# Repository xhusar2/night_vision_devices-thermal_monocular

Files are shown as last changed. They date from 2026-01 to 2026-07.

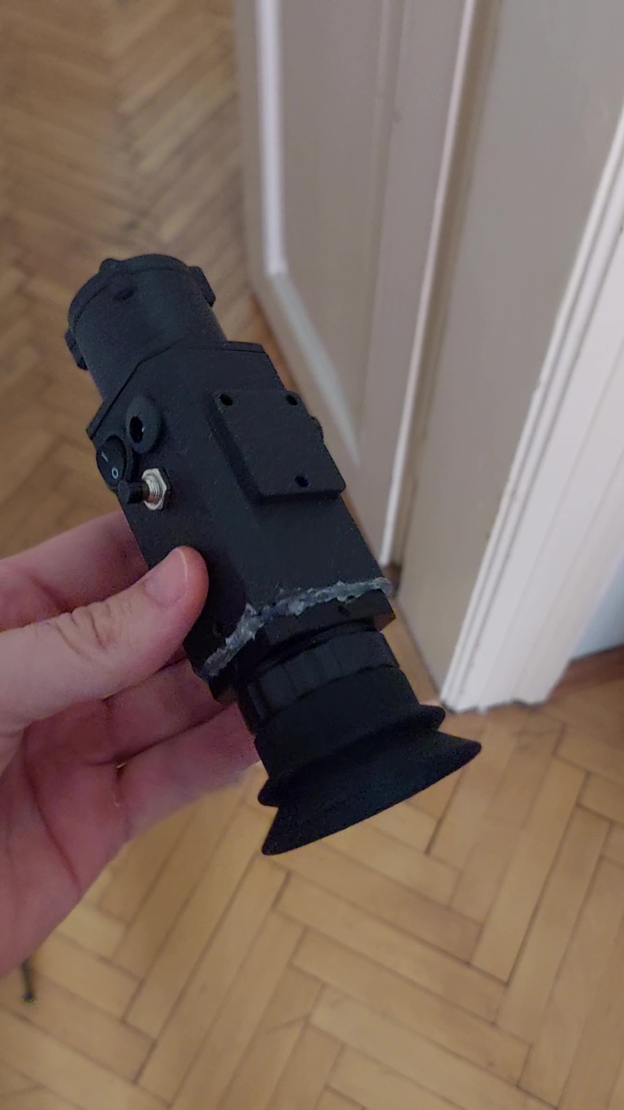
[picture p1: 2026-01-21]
resources/build_photos/finished_product_1.jpg

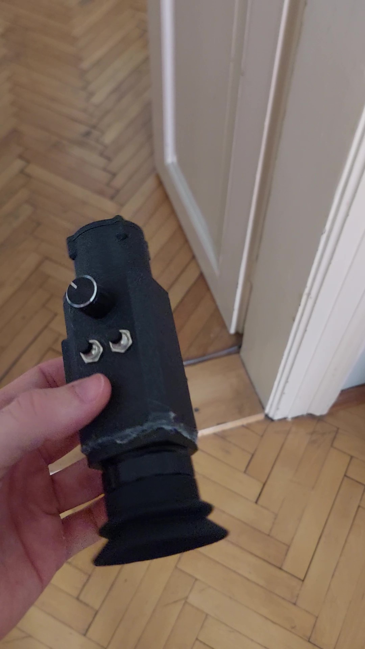
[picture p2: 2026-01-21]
resources/build_photos/finished_product_2.jpg

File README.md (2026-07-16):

# DIY Thermal Monocular — ESP32 + 256×192 Thermal Camera

> Build your own handheld thermal monocular for ~€400. Open-source firmware, 3D-printed body, RIS/Picatinny rail compatible.

<table>
  <tr>
    <td>Finished thermal monocular</td>
    <td>Thermal image result</td>
  </tr>
</table>

---

## What is this?

A fully functional **DIY thermal imaging monocular** built around a 256×192 thermal camera, an ESP32-C3 microcontroller, and a 0.39" OLED display — all packed into a 3D-printed body with an 18× eyepiece. It mounts on any standard Picatinny/RIS rail and costs a fraction of commercial thermal optics.

**Commercial thermal monoculars run €1,000–€5,000+. This build costs ~€400.**

---

## Features

- **256×192 thermal sensor** — 9mm lens, CVBS output
- **ESP32-C3** microcontroller with open-source firmware (ESP-IDF v5.5.3)
- **0.39" OLED display** with AV input — crisp image in the eyepiece
- **RIS/Picatinny rail mount** — fits standard rifle/observation setups
- **J-arm mount** option for head/helmet mounting
- **Wilcox mount** option for head/helmet mounting
- **Adjustable image orientation** — flip vertical/horizontal in firmware
- **Per-preset aiming controls** — toggle and position the crosshair from the web interface; each preset restores its saved state and position
- **Physical preset control** — release GPIO8 after a short press to change presets, or hold it for 2 seconds to toggle the current preset's crosshair
- **5.5×2.1mm DC power inlet** — run from external battery pack
- **3D-printed body** — printable on any FDM printer, all STLs included
- **Flashable via browser** — no toolchain needed for end users

---

## Specs

| Property | Value |
|---|---|
| Thermal sensor | 256×192, 9mm lens, CVBS |
| MCU | ESP32-C3 Super Mini |
| Display | 0.39" OLED (AV input) |
| Power | 5V via 5.5×2.1mm DC jack |
| Rail mount | Picatinny / RIS compatible |
| Firmware | ESP-IDF v5.5.3, open source |
| Total BOM cost | ~€400 |

---

## Repository Structure

```
├── docs/
│   ├── build-steps.md     # Full assembly guide
│   └── BOM.md             # Bill of materials with links
├── resources/
│   ├── wiring/            # KiCad schematic + PCB files
│   ├── build_photos/      # Build process photos
│   └── 3d_print/          # STL files for the body
├── compiled_binaries/     # Pre-built firmware — flash without a toolchain
└── source_code/           # ESP-IDF firmware source
```

---

## Quick Start

### Flash the pre-built firmware (no toolchain needed)

See [compiled_binaries/README.md](compiled_binaries/README.md) — flash directly from your browser or with `esptool.py`.

### Build & assemble

1. Order parts from the [Bill of Materials](docs/BOM.md)
2. Print the body STLs from `resources/3d_print/`
3. Follow the [Assembly Guide](docs/build-steps.md)

### Build firmware from source

```powershell
# In ESP-IDF CMD (Windows — use the Start Menu shortcut, not plain PowerShell)
cd source_code
idf.py set-target esp32c3
idf.py build
idf.py -p COM1 flash
```

---

## Wiring

Schematic and PCB files are in `resources/wiring/` (KiCad format). A PDF export is also included.

---

## Author

**Richard Husár** — [@xhusar2](https://github.com/xhusar2) — husarrichard@gmail.com

Licensed under the terms in [LICENSE](LICENSE).

---

## Credits

This project was inspired by [Jacob-OTW's BCOTI](https://github.com/Jacob-OTW/BCOTI/).
Many thanks for the great work that sparked this idea.

*Keywords: DIY thermal monocular, ESP32 thermal camera, open source thermal imaging, 3D printed thermal monocular, budget thermal optics, night vision DIY, OLED thermal viewer, ESP32-C3 thermal, Picatinny thermal scope*

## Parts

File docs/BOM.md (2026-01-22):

# Bill of Materials

> **Note:** Prices are approximate and may vary. Check AliExpress links for current pricing.

## Main Components

- **Thermal camera** (256x192 9MM CVBS) - ~€162.58 - [AliExpress Link](https://www.aliexpress.com/item/1005007938410808.html?spm=a2g0o.order_list.order_list_main.194.68141802FBvwr7)
- **ESP32 boards** (5PCS) - ~€2.69 - [AliExpress Link](https://www.aliexpress.com/item/1005007663345442.html?spm=a2g0o.order_list.order_list_main.209.68141802FBvwr7)
- **Eye piece** (18x) - ~€47.79 - [AliExpress Link](https://www.aliexpress.com/item/1005009392023314.html?spm=a2g0o.order_list.order_list_main.214.68141802FBvwr7)
- **0.39inch OLED display** (with AV 3Color) - ~€29.78 - [AliExpress Link](https://www.aliexpress.com/item/1005008087046449.html?spm=a2g0o.order_list.order_list_main.229.68141802FBvwr7)

## Electronics

- **Micro pins** (5pin 5set) - ~€2.32 - [AliExpress Link](https://www.aliexpress.com/item/1005008669994352.html?spm=a2g0o.order_list.order_list_main.204.68141802FBvwr7)
- **Buttons** (PBS-110 NO Black, 20pcs) - ~€3.82 - [AliExpress Link](https://www.aliexpress.com/item/1005008777027854.html?spm=a2g0o.order_list.order_list_main.224.68141802FBvwr7)
- **2-way DC power** (5.5x2.1mm) - ~€2.30 - [AliExpress Link](https://www.aliexpress.com/item/1005006375580065.html?spm=a2g0o.order_list.order_list_main.104.68141802HhpmVo)

## Total

**Total Cost:** ~€251.28

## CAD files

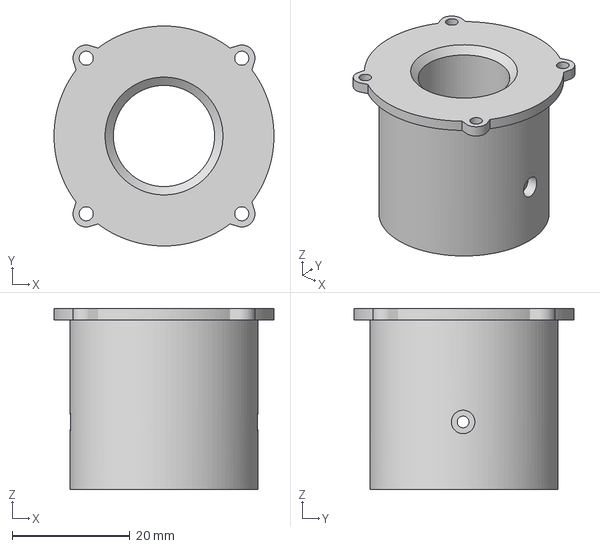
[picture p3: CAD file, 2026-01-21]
resources/3d_print/Thermal_housing_camarea_case.3mf
37.4 x 37.4 x 30.8 mm

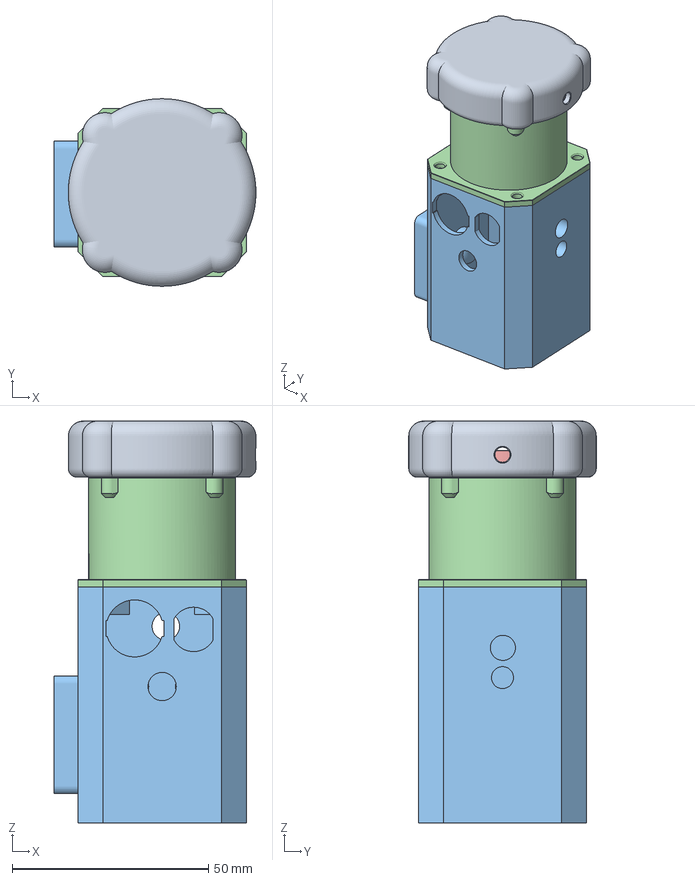
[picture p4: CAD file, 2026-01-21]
resources/3d_print/Thermal_housing.3mf
51.4 x 47.7 x 102.3 mm
Cap
Housing (1)
Main_body
Main_body_lid
Mesh_Protector

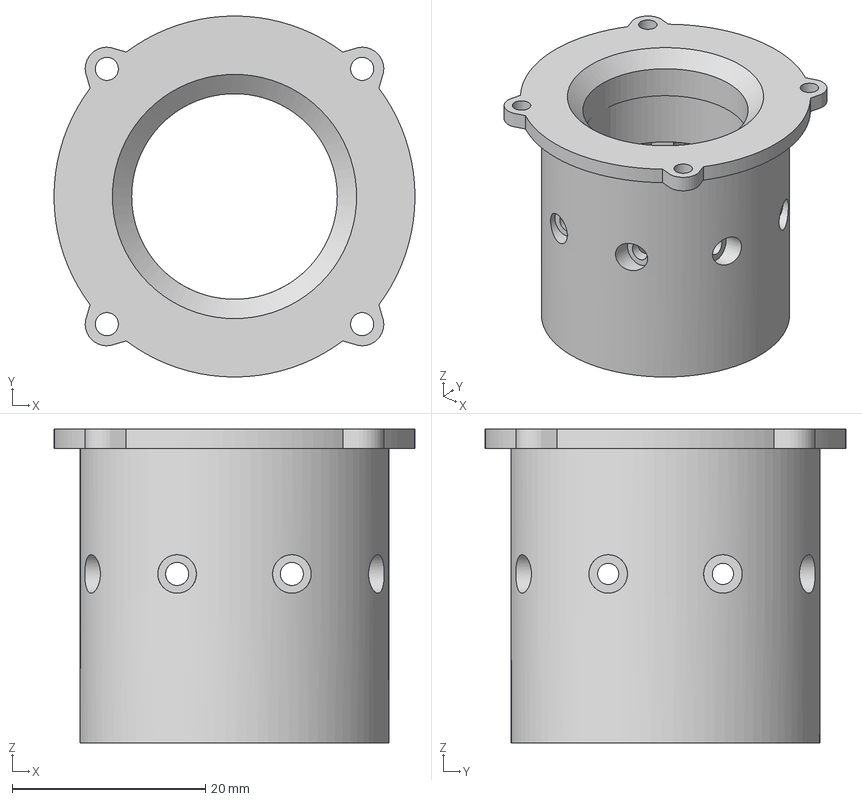
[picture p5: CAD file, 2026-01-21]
resources/3d_print/Thermal_camera_housing.3mf
37.4 x 37.4 x 32.5 mm

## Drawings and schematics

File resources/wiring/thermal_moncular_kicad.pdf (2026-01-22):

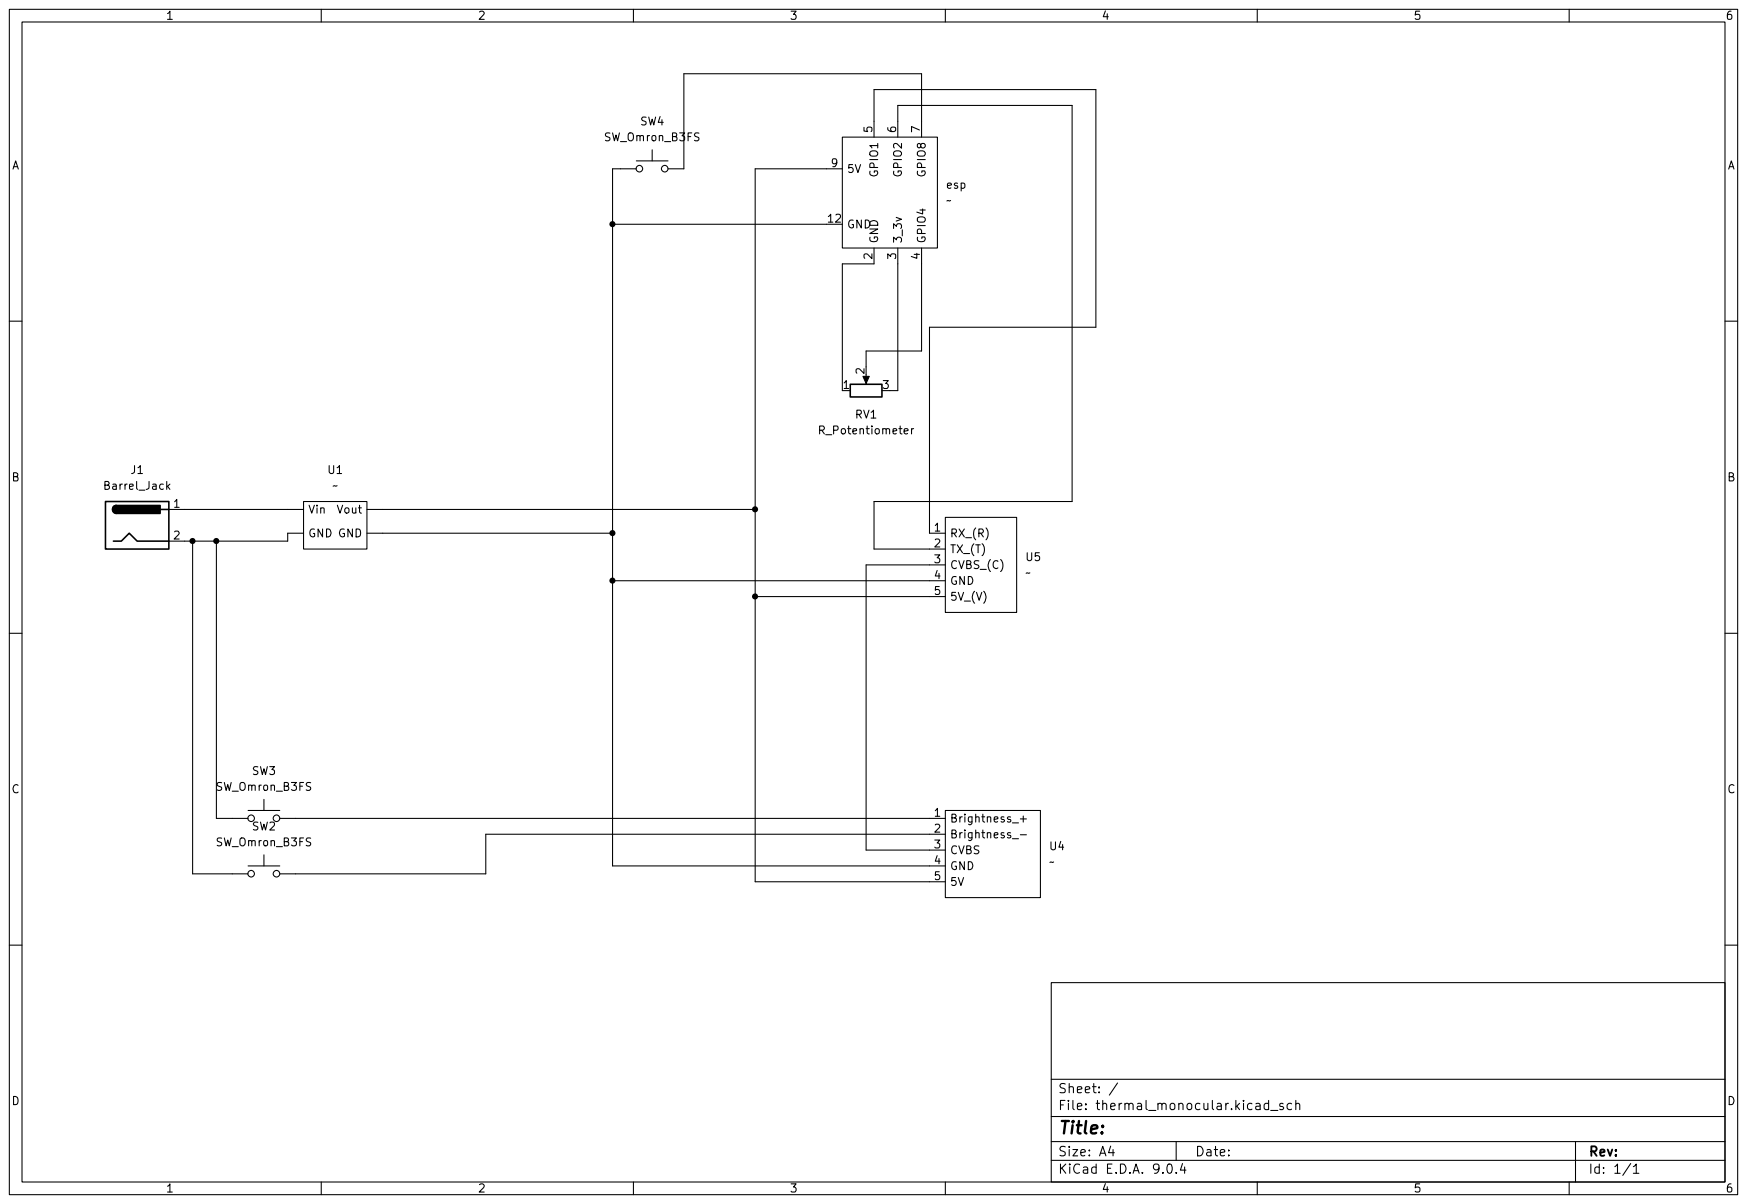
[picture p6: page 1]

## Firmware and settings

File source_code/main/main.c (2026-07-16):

#include <stdio.h>
#include <stdlib.h>
#include <string.h>
#include "esp_wifi.h"
#include "esp_mac.h"
#include "esp_event.h"
#include "lwip/err.h"
#include "lwip/sys.h"
#include "esp_log.h"
#include "nvs_flash.h"
#include "esp_http_server.h"
#include "esp_system.h"
#include "json_parser.h"
#include "esp_adc/adc_oneshot.h"
#include "esp_timer.h"
#include "driver/gpio.h"
#include "Mini2.h"
#include "control_validation.h"

#define TAG "MAIN"

#define SSID "THERMAL_MONOCULAR"
#define PASSWORD "password123"
#define PRESET_COUNT 3
#define FIRMWARE_VERSION "0.4.12"
#define BUTTON_DEBOUNCE_US (50 * 1000)
#define BUTTON_LONG_PRESS_US (2 * 1000 * 1000)
#define PERSIST_ATTEMPTS 3

#define UART_TX GPIO_NUM_1
#define UART_RX GPIO_NUM_2
#define POTI_PIN GPIO_NUM_4
#define MULTI_BTN GPIO_NUM_8


extern const uint8_t index_html_start[] asm("_binary_index_html_start");
extern const uint8_t index_html_end[]   asm("_binary_index_html_end");

static esp_netif_t *sta_netif = NULL;

nvs_handle_t flash_handle;

int8_t brightness_button_count = 0;

typedef struct stored_values_t{
    uint8_t active_preset;
    alignment_preset_t alignment;
    value_preset_t presets[PRESET_COUNT];
    bool first_boot;
} stored_values_t;

value_preset_t default_presets[] = {
    {
        .preset_en = true,
        .pseudo_color = WHOT,
        .scene_mode = GeneralMode,
        .contrast = 100,
        .edge_enhancment_gear = 1,
        .detail_enhancement_gear = 55,
        .burn_protection_en = true,
        .auto_shutter_en = true,
    },
    {
        .preset_en = true,
        .pseudo_color = WHOT,
        .scene_mode = Outline,
        .contrast = 100,
        .edge_enhancment_gear = 1,
        .detail_enhancement_gear = 50,
        .burn_protection_en = true,
        .auto_shutter_en = true,
    }
};

value_preset_t base_preset = {
    .preset_en = false,
    .pseudo_color = WHOT,
    .scene_mode = GeneralMode,
    .contrast = 50,
    .edge_enhancment_gear = 1,
    .detail_enhancement_gear = 50,
    .burn_protection_en = true,
    .auto_shutter_en = true,
};

stored_values_t stored = {
    .active_preset = 0,
    .alignment = {
        .zoom = 10,
        .zoom_x = 128,
        .zoom_y = 96,
        .av_format = PAL,
        .flip_mode = No_Flip,
        .fps = Hz50,
        .refresh_flip_mode = false,
    },
    .first_boot = true
};

static uint8_t crosshair_preset_mask = 0;
typedef struct {
    uint16_t x[PRESET_COUNT];
    uint16_t y[PRESET_COUNT];
} crosshair_positions_t;
static crosshair_positions_t crosshair_positions = {
    .x = {128, 128, 128},
    .y = {96, 96, 96},
};
typedef struct {
    uint8_t spatial[PRESET_COUNT];
    uint8_t temporal[PRESET_COUNT];
    uint8_t gamma[PRESET_COUNT];
    uint8_t spatial_mask;
    uint8_t temporal_mask;
    uint8_t gamma_mask;
} image_controls_t;
static image_controls_t image_controls;
static bool wifi_next_boot = false;
static esp_err_t boot_analog_video_initial_status = ESP_ERR_INVALID_STATE;
static volatile uint8_t last_applied_preset;
static bool camera_state_authoritative = true;
static esp_err_t camera_state_status = ESP_OK;
static bool persistence_authoritative = true;
static esp_err_t persistence_status = ESP_OK;

static bool preset_crosshair_enabled(uint8_t preset) {
    return (crosshair_preset_mask & (1U << preset)) != 0;
}

static void set_preset_crosshair_enabled(uint8_t preset, bool enabled) {
    if (enabled) {
        crosshair_preset_mask |= (1U << preset);
    } else {
        crosshair_preset_mask &= ~(1U << preset);
    }
}

static esp_err_t commit_settings(void) {
    esp_err_t err = nvs_set_blob(flash_handle, "stored_values", &stored, sizeof(stored));
    if (err == ESP_OK) {
        err = nvs_set_u8(flash_handle, "crosshair_mask", crosshair_preset_mask);
    }
    if (err == ESP_OK) {
        err = nvs_set_u8(flash_handle, "wifi_next", wifi_next_boot);
    }
    if (err == ESP_OK) {
        err = nvs_set_blob(flash_handle, "image_controls", &image_controls, sizeof(image_controls));
    }
    if (err == ESP_OK) {
        err = nvs_set_blob(flash_handle, "cursor_pos", &crosshair_positions, sizeof(crosshair_positions));
    }
    return err == ESP_OK ? nvs_commit(flash_handle) : err;
}

static int persist_settings(void *context) {
    (void)context;
    return commit_settings();
}

static esp_err_t commit_settings_with_retry(void) {
    return control_retry_operation(NULL, persist_settings, PERSIST_ATTEMPTS);
}

static bool json_obj_has_key(const jparse_ctx_t *jctx, const char *key) {
    const int object_index = jctx->cur - jctx->tokens;
    const size_t key_length = strlen(key);

    for (int i = object_index + 1; i < jctx->num_tokens; i++) {
        const json_tok_t *token = &jctx->tokens[i];
        if (token->parent == object_index && token->type == JSMN_STRING &&
            (size_t)(token->end - token->start) == key_length &&
            strncmp(jctx->js + token->start, key, key_length) == 0) {
            return true;
        }
    }

    return false;
}

Mini2_t cam = {
    .uart_port = UART_NUM_1, // C3 only has num0 and num1, and num0 is used for debug / USB_CDC
    .uart_tx = UART_TX,
    .uart_rx = UART_RX,
    .variant = Mini2_256
};

static int apply_preset_step(void *context, uint8_t preset) {
    Mini2_t *camera = context;
    return Mini2_apply_preset(camera, &stored.presets[preset], &stored.alignment, true);
}

static int apply_crosshair_step(void *context, bool enabled) {
    return Mini2_set_crosshair(context, enabled);
}

static esp_err_t apply_preset_with_crosshair(uint8_t preset) {
    esp_err_t err = control_apply_preset_transaction(
        &cam, preset, preset_crosshair_enabled(preset),
        apply_preset_step, apply_crosshair_step);
    if (err != ESP_OK) {
        return err;
    }
    err = Mini2_set_crosshair_position(&cam, crosshair_positions.x[preset],
                                       crosshair_positions.y[preset]);
    if (image_controls.spatial_mask & (1U << preset))
        err = Mini2_set_spatial_noise_reduction(&cam, image_controls.spatial[preset]);
    if (err == ESP_OK && (image_controls.temporal_mask & (1U << preset)))
        err = Mini2_set_temporal_noise_reduction(&cam, image_controls.temporal[preset]);
    if (err == ESP_OK && (image_controls.gamma_mask & (1U << preset)))
        err = Mini2_set_gamma_intensity(&cam, image_controls.gamma[preset]);
    if (err != ESP_OK) return err;
    last_applied_preset = preset;
    return ESP_OK;
}

static esp_err_t restore_camera_snapshot(const stored_values_t *snapshot,
                                         uint8_t snapshot_crosshair_mask) {
    const uint8_t preset_index = snapshot->active_preset;
    const value_preset_t *preset = &snapshot->presets[preset_index];
    esp_err_t err = ESP_OK;

    err = control_first_error(err, Mini2_set_color_pallet(&cam, preset->pseudo_color));
    err = control_first_error(err, Mini2_set_scene_mode(&cam, preset->scene_mode));
    err = control_first_error(err, Mini2_set_contrast(&cam, preset->contrast));
    err = control_first_error(err, Mini2_set_edge_enhancment(&cam, preset->edge_enhancment_gear));
    err = control_first_error(err, Mini2_set_detail_enhancement(&cam, preset->detail_enhancement_gear));
    err = control_first_error(err, Mini2_set_burn_protection(&cam, preset->burn_protection_en));
    err = control_first_error(err, Mini2_set_auto_shutter(&cam, preset->auto_shutter_en));
    if (image_controls.spatial_mask & (1U << preset_index))
        err = control_first_error(err, Mini2_set_spatial_noise_reduction(&cam, image_controls.spatial[preset_index]));
    if (image_controls.temporal_mask & (1U << preset_index))
        err = control_first_error(err, Mini2_set_temporal_noise_reduction(&cam, image_controls.temporal[preset_index]));
    if (image_controls.gamma_mask & (1U << preset_index))
        err = control_first_error(err, Mini2_set_gamma_intensity(&cam, image_controls.gamma[preset_index]));
    err = control_first_error(err, Mini2_set_analog_video_format(&cam, snapshot->alignment.av_format));
    err = control_first_error(err, Mini2_set_flip_mode(&cam, snapshot->alignment.flip_mode));
    err = control_first_error(err, Mini2_set_point_zoom(
        &cam, snapshot->alignment.zoom_x, snapshot->alignment.zoom_y,
        snapshot->alignment.zoom));
    err = control_first_error(err, Mini2_set_crosshair(
        &cam, (snapshot_crosshair_mask & (1U << preset_index)) != 0));
    err = control_first_error(err, Mini2_set_crosshair_position(
        &cam, crosshair_positions.x[preset_index], crosshair_positions.y[preset_index]));

    if (err == ESP_OK) {
        last_applied_preset = preset_index;
    }
    return err;
}

static void wifi_event_handler(void* arg, esp_event_base_t event_base, int32_t event_id, void* event_data) {
    if (event_id == WIFI_EVENT_AP_STACONNECTED) {
        wifi_event_ap_staconnected_t* event = (wifi_event_ap_staconnected_t*) event_data;
        ESP_LOGI(TAG, "station "MACSTR" join, AID=%d",
                 MAC2STR(event->mac), event->aid);
    } else if (event_id == WIFI_EVENT_AP_STADISCONNECTED) {
        wifi_event_ap_stadisconnected_t* event = (wifi_event_ap_stadisconnected_t*) event_data;
        ESP_LOGI(TAG, "station "MACSTR" leave, AID=%d, reason=%d",
                 MAC2STR(event->mac), event->aid, event->reason);
    }
}

static uint8_t next_preset(uint8_t current) {
    do {
        current = (current + 1) % PRESET_COUNT;
    } while (current != 0 && !stored.presets[current].preset_en);
    return current;
}

static esp_err_t switch_preset(uint8_t preset) {
    const stored_values_t previous = stored;
    const uint8_t previous_crosshair_mask = crosshair_preset_mask;
    esp_err_t err = apply_preset_with_crosshair(preset);
    if (err == ESP_OK) {
        stored.active_preset = preset;
        camera_state_authoritative = true;
        camera_state_status = ESP_OK;
    } else {
        esp_err_t rollback_err = restore_camera_snapshot(&previous, previous_crosshair_mask);
        camera_state_authoritative = rollback_err == ESP_OK;
        camera_state_status = rollback_err == ESP_OK ? err : rollback_err;
        ESP_LOGE(TAG, "Preset %u apply failed (%s), rollback %s", preset,
                 esp_err_to_name(err), rollback_err == ESP_OK ? "succeeded" : "failed");
    }
    return err;
}


static esp_err_t rollback_preset(uint8_t preset) {
    stored_values_t snapshot = stored;
    snapshot.active_preset = preset;
    esp_err_t err = restore_camera_snapshot(&snapshot, crosshair_preset_mask);
    if (err == ESP_OK) {
        stored = snapshot;
        esp_err_t commit_err = commit_settings_with_retry();
        persistence_authoritative = control_commit_is_authoritative(commit_err);
        persistence_status = commit_err;
    }
    camera_state_authoritative = err == ESP_OK;
    camera_state_status = err;
    return err;
}
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
void app_main(void) {
    ESP_ERROR_CHECK(nvs_flash_init());

    for (int i=0; i<PRESET_COUNT; i++) {
        stored.presets[i] = i < (sizeof(default_presets) / sizeof(value_preset_t))
            ? default_presets[i] : base_preset;
    }

    ESP_ERROR_CHECK(nvs_open("storage", NVS_READWRITE, &flash_handle));
    size_t len = sizeof(stored_values_t);
    esp_err_t err = nvs_get_blob(flash_handle, "stored_values", &stored, &len);
    if (err != ESP_OK) {
        ESP_LOGI(TAG, "Failed to read stored values from NVS, going with defaults.");
    }
    uint8_t persisted_value = 0;
    if (nvs_get_u8(flash_handle, "crosshair_mask", &persisted_value) == ESP_OK) {
        crosshair_preset_mask = persisted_value & ((1U << PRESET_COUNT) - 1U);
    } else if (nvs_get_u8(flash_handle, "crosshair_en", &persisted_value) == ESP_OK && persisted_value != 0) {
        crosshair_preset_mask = (1U << PRESET_COUNT) - 1U;
    }
    size_t image_controls_len = sizeof(image_controls);
    if (nvs_get_blob(flash_handle, "image_controls", &image_controls,
                     &image_controls_len) != ESP_OK ||
        image_controls_len != sizeof(image_controls)) {
        memset(&image_controls, 0, sizeof(image_controls));
    }
    size_t cursor_positions_len = sizeof(crosshair_positions);
    uint8_t cursor_migrated = 0;
    if (nvs_get_blob(flash_handle, "cursor_pos", &crosshair_positions,
                     &cursor_positions_len) != ESP_OK ||
        cursor_positions_len != sizeof(crosshair_positions)) {
        for (int i = 0; i < PRESET_COUNT; i++) {
            crosshair_positions.x[i] = stored.alignment.zoom_x < cam.variant.sensor_width
                ? stored.alignment.zoom_x : cam.variant.sensor_width - 1;
            crosshair_positions.y[i] = stored.alignment.zoom_y < cam.variant.sensor_height
                ? stored.alignment.zoom_y : cam.variant.sensor_height - 1;
        }
    }
    if (nvs_get_u8(flash_handle, "cursor_migrated", &cursor_migrated) != ESP_OK ||
        cursor_migrated == 0) {
        stored.alignment.zoom = 10;
        stored.alignment.zoom_x = cam.variant.sensor_width / 2;
        stored.alignment.zoom_y = cam.variant.sensor_height / 2;
        ESP_ERROR_CHECK(nvs_set_u8(flash_handle, "cursor_migrated", 1));
        ESP_ERROR_CHECK(commit_settings());
    }
    persisted_value = 0;
    if (nvs_get_u8(flash_handle, "wifi_next", &persisted_value) == ESP_OK) {
        wifi_next_boot = persisted_value != 0;
    }

    gpio_config_t io_conf = {
        .intr_type = GPIO_INTR_DISABLE,
        .mode = GPIO_MODE_INPUT,
        .pin_bit_mask = (1ULL << MULTI_BTN),
        .pull_down_en = GPIO_PULLDOWN_DISABLE,
        .pull_up_en = GPIO_PULLUP_ENABLE,
    };
    gpio_config(&io_conf);

    bool wifi_en = (gpio_get_level(MULTI_BTN) == 0) || stored.first_boot || wifi_next_boot;
    if (wifi_next_boot) {
        wifi_next_boot = false;
        ESP_ERROR_CHECK(commit_settings());
    }
    ESP_LOGI(TAG, "Wifi: %d", (int)wifi_en);

    if (wifi_en) {
        ESP_ERROR_CHECK(esp_netif_init());
        ESP_ERROR_CHECK(esp_event_loop_create_default());
        sta_netif = esp_netif_create_default_wifi_ap();
        wifi_init_config_t cfg = WIFI_INIT_CONFIG_DEFAULT();
        ESP_ERROR_CHECK(esp_wifi_init(&cfg));
        ESP_ERROR_CHECK(esp_event_handler_instance_register(WIFI_EVENT,
                                                        ESP_EVENT_ANY_ID,
                                                        &wifi_event_handler,
                                                        NULL,
                                                        NULL));
        wifi_config_t wifi_config = {
            .ap = {
                .ssid = SSID,
                .ssid_len = strlen(SSID),
                .password = PASSWORD,
                .channel = 1,
                .max_connection = 4,
                .authmode = WIFI_AUTH_WPA2_PSK,
                .pmf_cfg = {
                    .required = true,
                },
            }
        };
        ESP_ERROR_CHECK(esp_wifi_set_mode(WIFI_MODE_AP));
        ESP_ERROR_CHECK(esp_wifi_set_config(WIFI_IF_AP, &wifi_config) );
        ESP_ERROR_CHECK(esp_wifi_start());
    }

    ESP_LOGI(TAG, "Waiting 5000 ms before Mini2 UART initialization");
    vTaskDelay(pdMS_TO_TICKS(5000));
    Mini2_init(&cam);
    ESP_LOGI(TAG, "Mini2 UART initialized at %lld ms", esp_timer_get_time() / 1000);

    boot_analog_video_initial_status = Mini2_apply_preset(&cam, &stored.presets[stored.active_preset], &stored.alignment, false);
    if (boot_analog_video_initial_status == ESP_OK) {
        ESP_LOGI(TAG, "Mini2 boot warm-up started at %lld ms", esp_timer_get_time() / 1000);
        vTaskDelay(pdMS_TO_TICKS(2500));
        ESP_LOGI(TAG, "Mini2 boot warm-up completed at %lld ms", esp_timer_get_time() / 1000);
        boot_analog_video_initial_status = Mini2_set_crosshair(&cam, preset_crosshair_enabled(stored.active_preset));
    }
    if (boot_analog_video_initial_status == ESP_OK) {
        boot_analog_video_initial_status = Mini2_set_crosshair_position(
            &cam, crosshair_positions.x[stored.active_preset],
            crosshair_positions.y[stored.active_preset]);
    }
    if (boot_analog_video_initial_status == ESP_OK &&
        (image_controls.spatial_mask & (1U << stored.active_preset)))
        boot_analog_video_initial_status = Mini2_set_spatial_noise_reduction(&cam, image_controls.spatial[stored.active_preset]);
    if (boot_analog_video_initial_status == ESP_OK &&
        (image_controls.temporal_mask & (1U << stored.active_preset)))
        boot_analog_video_initial_status = Mini2_set_temporal_noise_reduction(&cam, image_controls.temporal[stored.active_preset]);
    if (boot_analog_video_initial_status == ESP_OK &&
        (image_controls.gamma_mask & (1U << stored.active_preset)))
        boot_analog_video_initial_status = Mini2_set_gamma_intensity(&cam, image_controls.gamma[stored.active_preset]);
    last_applied_preset = stored.active_preset;
    if (boot_analog_video_initial_status == ESP_OK) {
        camera_state_authoritative = true;
        camera_state_status = ESP_OK;
        ESP_LOGI(TAG, "Boot video save/apply initialization succeeded");
    } else {
        camera_state_authoritative = false;
        camera_state_status = boot_analog_video_initial_status;
        ESP_LOGE(TAG, "Boot video save/apply initialization failed: %s", esp_err_to_name(boot_analog_video_initial_status));
    }
    xTaskCreate(loop_task, "loop task", 16384, NULL, 5, NULL);

    if (wifi_en) {
        httpd_handle_t server = NULL;
        httpd_config_t config = HTTPD_DEFAULT_CONFIG();
        config.lru_purge_enable = true;

        ESP_LOGI(TAG, "Starting server on port: '%d'", config.server_port);
        if (httpd_start(&server, &config) == ESP_OK) {
            ESP_LOGI(TAG, "Registering URI handlers");
            httpd_register_uri_handler(server, &echo);
            httpd_register_uri_handler(server, &index_uri);
            httpd_register_uri_handler(server, &retireve_values_route);
        }
    }

}

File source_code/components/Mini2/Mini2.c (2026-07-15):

#include "Mini2.h"

uint16_t crc16_xmodem(uint8_t* data, size_t len) {
    uint16_t crc = 0;
    for (int i=0; i<len; i++) {
        crc ^= (data[i] << 8);
        for (int j=0; j<8; j++) {
            if (crc & 0x8000) {
                crc = (crc << 1) ^ 0x1021;
            } else {
                crc <<= 1;
            }
        }
    }
    return crc;
}

void Mini2_init(Mini2_t* cam) {
    uart_config_t uart_config = {
        .baud_rate = 115200,
        .data_bits = UART_DATA_8_BITS,
        .parity = UART_PARITY_DISABLE,
        .stop_bits = UART_STOP_BITS_1,
        .flow_ctrl = UART_HW_FLOWCTRL_DISABLE,
        .source_clk = UART_SCLK_DEFAULT,
    };

    ESP_ERROR_CHECK(uart_driver_install(cam->uart_port, 2048, 0, 0, NULL, 0));
    ESP_ERROR_CHECK(uart_param_config(cam->uart_port, &uart_config));
    ESP_ERROR_CHECK(uart_set_pin(cam->uart_port, cam->uart_tx, cam->uart_rx, -1, -1));
}

esp_err_t Mini2_write_command(Mini2_t* cam, uint8_t* cmd, size_t len) {
    uint8_t full_cmd[] = {0x55, 0x43, 0x49, 0x12, 0x00, 0x00 /*command class*/, 0x00 /*command index*/, 0x00 /*sub command*/, 0x00 /*reserved*/, 0x00, 0x00, 0x00, 0x00 /*4byte Parameter1*/, 0x00, 0x00, 0x00, 0x00 /*4byte Parameter2*/, 0x00, 0x00 /*Read length, 0 when writing*/, 0x00, 0x00 /*2btyes Reserved*/, 0x00, 0x00 /*2byte crc16 xmodem*/};

    if (len > 16) {
        ESP_LOGE(Mini2_TAG, "command length may not be longer than 16bytes");
        return ESP_FAIL;
    }

    memcpy(full_cmd + 5, cmd, len);
    uint16_t checksum = crc16_xmodem(full_cmd + 5, 16);
    memcpy(full_cmd + 21, &checksum, 2);

    ESP_LOG_BUFFER_HEXDUMP(Mini2_TAG, full_cmd, sizeof(full_cmd), ESP_LOG_INFO);
    
    for (int i=0; i < sizeof(full_cmd); i++) {
        int bytes_written = uart_write_bytes(cam->uart_port, full_cmd + i, 1);
        if (bytes_written == -1) {
            ESP_LOGE(Mini2_TAG, "Failed to write byte%d command to UART", i);
            return ESP_FAIL;
        }   
    }

    return ESP_OK;
}

esp_err_t Mini2_read_command(Mini2_t* cam, uint8_t* cmd, size_t len, uint8_t* out_buf, size_t* out_len) {
    esp_err_t err_code;
    const size_t expected_len = *out_len;

    memset(out_buf, 0, expected_len);

    uart_flush(cam->uart_port);
    err_code = Mini2_write_command(cam, cmd, len);
    if (err_code != ESP_OK) {
        return err_code;
    }
    int bytes_read = uart_read_bytes(cam->uart_port, out_buf, *out_len, pdMS_TO_TICKS(200));
    if (bytes_read <= 0 || (size_t)bytes_read != expected_len) {
        *out_len = bytes_read > 0 ? (size_t)bytes_read : 0;
        return ESP_FAIL;
    }

    ESP_LOG_BUFFER_HEXDUMP("UART_READ", out_buf, bytes_read, ESP_LOG_INFO);

    *out_len = bytes_read;
    return ESP_OK;
}

esp_err_t Mini2_get_flip_mode(Mini2_t* cam, enum FlipMode* flip_mode_out) {
    uint8_t rx_buffer[10];
    size_t len = sizeof(rx_buffer);

    uint8_t cmd[] = {0x10, 0x10, 0x83, 0x00, 0x00, 0x00, 0x00, 0x00, 0x00, 0x00, 0x00, 0x00, 0x01};
    esp_err_t err_code = Mini2_read_command(cam, cmd, sizeof(cmd), rx_buffer, &len);
    if (err_code != ESP_OK) {
        return err_code;
    }
    
    if (!(rx_buffer[0] == 0xBE && rx_buffer[1] == 0xAA && rx_buffer[8] == 0xEB && rx_buffer[9] == 0xAA)) {
        return ESP_FAIL;
    }

    *flip_mode_out = (enum FlipMode)rx_buffer[5];
    return ESP_OK;
}

esp_err_t Mini2_set_color_pallet(Mini2_t* cam, enum PseudoColor pseudo_color) {
    uint8_t cmd[] = {0x10, 0x03, 0x45, 0x00, 0x00, pseudo_color};
    return Mini2_write_command(cam, cmd, sizeof(cmd));
}

esp_err_t Mini2_set_scene_mode(Mini2_t* cam, enum SceneMode scene_mode) {
    uint8_t cmd[] = {0x10, 0x04, 0x42, 0x00, scene_mode};
    return Mini2_write_command(cam, cmd, sizeof(cmd));
}

esp_err_t Mini2_set_flip_mode(Mini2_t* cam, enum SceneMode FlipMode) {
    uint8_t cmd[] = {0x10, 0x10, 0x43, 0x00, FlipMode};
    return Mini2_write_command(cam, cmd, sizeof(cmd));
}

esp_err_t Mini2_set_analog_video_format(Mini2_t* cam, enum AnalogVideoFormat av_format) {
    uint8_t cmd[] = {0x10, 0x10, 0x4A, 0x00, 0x01, av_format};
    return Mini2_write_command(cam, cmd, sizeof(cmd));
}

esp_err_t Mini2_get_analog_video_format(Mini2_t* cam, enum AnalogVideoFormat* av_format_out) {
    uint8_t rx_buffer[11] = {0};
    size_t len = sizeof(rx_buffer);

    uint8_t cmd[] = {0x10, 0x10, 0x8a, 0x00, 0x00, 0x00, 0x00, 0x00, 0x00, 0x00, 0x00, 0x00, 0x02};
    esp_err_t err_code = Mini2_read_command(cam, cmd, sizeof(cmd), rx_buffer, &len);
    if (err_code != ESP_OK) {
        return err_code;
    }

    if (!(rx_buffer[0] == 0xBE && rx_buffer[1] == 0xAA && rx_buffer[9] == 0xEB && rx_buffer[10] == 0xAA)) {
        return ESP_FAIL;
    }

    *av_format_out = (enum AnalogVideoFormat)rx_buffer[6];
    return ESP_OK;
}

esp_err_t Mini2_set_digital_video_format(Mini2_t* cam, bool enabled, enum DigitalVideoFormat video_format, enum DetectorRefreshRate fps) {
    uint8_t cmd[] = {0x10, 0x10, 0x46, 0x00, (uint8_t)enabled, (uint8_t)video_format, (uint8_t)fps};
    return Mini2_write_command(cam, cmd, sizeof(cmd));
}

esp_err_t Mini2_save_video(Mini2_t* cam) {
    uint8_t cmd[] = {0x10, 0x10, 0x49};
    return Mini2_write_command(cam, cmd, sizeof(cmd));
}

esp_err_t Mini2_set_brightness(Mini2_t* cam, uint8_t brightness) {
    if (brightness > 100) {
        ESP_LOGE(Mini2_TAG, "Brightness must be <= 100");
        return ESP_FAIL;
    }
    uint8_t cmd[] = {0x10, 0x04, 0x47, 0x00, brightness};
    return Mini2_write_command(cam, cmd, sizeof(cmd));
}

esp_err_t Mini2_set_contrast(Mini2_t* cam, uint8_t contrast) {
    if (contrast > 100) {
        ESP_LOGE(Mini2_TAG, "Contrast must be <= 100");
        return ESP_FAIL;
    }
    uint8_t cmd[] = {0x10, 0x04, 0x4A, 0x00, contrast};
    return Mini2_write_command(cam, cmd, sizeof(cmd));
}

esp_err_t Mini2_set_edge_enhancment(Mini2_t* cam, uint8_t gear) {
    if (gear > 2) {
        ESP_LOGE(Mini2_TAG, "Edge enhancment gear must be <= 2");
        return ESP_FAIL;
    }
    uint8_t cmd[] = {0x10, 0x04, 0x4E, 0x00, gear};
    return Mini2_write_command(cam, cmd, sizeof(cmd));
}

esp_err_t Mini2_set_detail_enhancement(Mini2_t* cam, uint8_t gear) {
    if (gear > 100) {
        ESP_LOGE(Mini2_TAG, "Detail enhancement gear must be <= 100");
        return ESP_FAIL;
    }
    uint8_t cmd[] = {0x10, 0x04, 0x45, 0x00, gear};
    return Mini2_write_command(cam, cmd, sizeof(cmd));
}

esp_err_t Mini2_set_spatial_noise_reduction(Mini2_t* cam, uint8_t value) {
    uint8_t cmd[] = {0x10, 0x04, 0x4B, 0x00, value};
    return Mini2_write_command(cam, cmd, sizeof(cmd));
}

esp_err_t Mini2_set_temporal_noise_reduction(Mini2_t* cam, uint8_t value) {
    uint8_t cmd[] = {0x10, 0x04, 0x4C, 0x00, value};
    return Mini2_write_command(cam, cmd, sizeof(cmd));
}

esp_err_t Mini2_set_gamma_intensity(Mini2_t* cam, uint8_t value) {
    uint8_t cmd[] = {0x10, 0x04, 0x4D, 0x00, value};
    return Mini2_write_command(cam, cmd, sizeof(cmd));
}
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

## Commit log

2026-01-21 init commit
    [Thermal_camera_housing.3mf, Thermal_housing.3mf, Thermal_housing_camarea_case.3mf]
2026-01-22 add kicad wiring
    [thermal_monocular.kicad_pcb, thermal_monocular.kicad_sch]
2026-01-22 Add Bill of Materials documentation and reference in README
2026-07-15 no-mistakes(review): Validate controls and synchronize actual device state
    [main.c]
2026-07-15 no-mistakes(review): Reject malformed crosshair toggle requests
    [main.c]
2026-07-15 fix(display): preserve video initialization
    [main.c]
2026-07-15 no-mistakes(test): Initialize analog video output reliably at boot
    [Mini2.c]
2026-07-15 no-mistakes(test): Expose boot video diagnostics and gate aim controls
    [Mini2.c, main.c]
2026-07-15 no-mistakes(test): Persist settings and delay boot video activation
    [main.c]
2026-07-15 no-mistakes(test): Fix state sync and boot video activation
    [main.c, test_control_validation.c]
2026-07-15 no-mistakes(test): Delay boot video recovery and restore crosshair state
    [main.c, test_control_validation.c]
2026-07-15 no-mistakes(test): Restore working boot video and 1.0× aiming
    [Mini2.c, main.c, test_control_validation.c]
2026-07-15 no-mistakes(test): Restore camera readiness timing and aim crop controls
    [Mini2.c, main.c, test_control_validation.c]
2026-07-15 no-mistakes(test): Restore working boot video save/apply sequence
    [Mini2.c, main.c, test_control_validation.c]
2026-07-15 no-mistakes(test): Fix UART reads and analog video reliability
    [Mini2.c, main.c, test_control_validation.c]
2026-07-15 no-mistakes(review): Fix transactional presets and stable button debounce
    [main.c, test_control_validation.c]
2026-07-15 no-mistakes(review): Add authoritative rollback and persistence retries
    [main.c, test_control_validation.c]
2026-07-15 no-mistakes(review): Make web controls authoritative and transactional
    [main.c, test_control_validation.c]
2026-07-15 no-mistakes(review): Restore exact camera state during rollback
    [main.c, test_control_validation.c]
2026-07-15 no-mistakes(review): Gate rollback on successful hardware mutation
    [main.c, test_control_validation.c]
2026-07-15 no-mistakes(review): Track camera and persistence authority separately
    [main.c, test_control_validation.c]
2026-07-15 no-mistakes(test): Add persistent Mini2 image controls
    [Mini2.c, main.c, test_control_validation.c]
2026-07-15 no-mistakes(test): Add persistent native crosshair positioning
    [Mini2.c, main.c, test_control_validation.c]
2026-07-16 no-mistakes(test): Restore reliable boot video initialization
    [Mini2.c, main.c, test_control_validation.c]
2026-07-16 no-mistakes(test): Restore known-good boot video initialization
    [Mini2.c, main.c, test_control_validation.c]
2026-07-16 no-mistakes(test): Protect boot UART commands with warm-up delay
    [main.c, test_control_validation.c]
